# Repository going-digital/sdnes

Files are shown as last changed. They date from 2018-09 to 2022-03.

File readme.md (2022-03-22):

# SDnes
## An internal SD card modification for the Nintendo NES/SNES/Famicom/SuperFamicom classic consoles

This design is a mod-board that solders directly onto the PCB. This board allows the console to a Micro-SD card. This works well with [Hakchi](https://github.com/TeamShinkansen/hakchi2) and the tools at [Hakchi Resources](https://hakchiresources.com). The board is designed with [KiCad 5](http://kicad.org).

It is:
  * Cheap
  * Home solderable (although you will need a fine tip)
  * Compatible with Hakchi firmware
  * Tidy
  * Open source
  * NOT easy to solder. The minimal install requires soldering pads that are 1mm apart. If you are used to soldering surface mount, no problem. If not, this should not be your first project. (But it is open source, so if you want to flood eBay with them, be my guest!)
  * NOT as convenient as a ready-made board.
  * NOT suitable for users who often remove their MicroSD card. I use Hakchi to make changes remotely over USB or WiFi instead.

# Alternatives
  * [Super Storage](https://echo10.io) is a fully assembled board that allows much easier access.
  * [SD breakout boards can be handwired.](https://wiki.hakchi.net/Adding_an_Internal_SD_Card)
  * For ultimate cheapness, an SD to microSD adapter makes a functional breakout board, and everyone has a spare.

# Bill of Materials
There are two versions of this mod. If your console main board has the marking "FTM-NES", you will need the NES version. If it is marked "FTM-SHVC", you will need the SHVC version. The other components are the same.

| Component | Description | Source |
|-|-|-|
|SK1|Molex 500901-0801|RS:670-2430, Farnell:1344008, Digikey:WM19081CT-ND, Mouser:538-500901-0801, [Octopart](https://octopart.com/search?q=500901-0801)|
|PCB NES|PCB|[Oshpark](https://oshpark.com/shared_projects/vaCz66J4) or [your chosen fabricator.](https://github.com/going-digital/sdnes/tree/master/nes/fabrication)|
|or PCB SHVC|PCB|[Oshpark](https://oshpark.com/shared_projects/LHg9E5QS) or [your chosen fabricator.](https://github.com/going-digital/sdnes/tree/master/shvc/fabrication)|

Optionally card access indicator: Fit R1 (1Kohm, 0603) and D1 (Red LED, 0603).

Optional decoupling: Fit C1 (100nF, 0603)

# Fitting the NES version
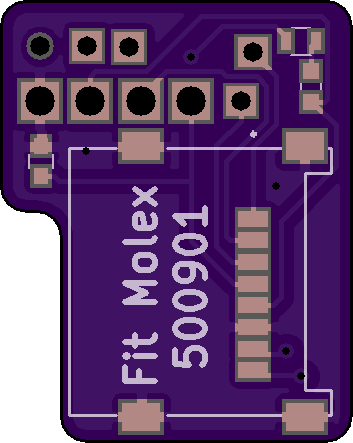
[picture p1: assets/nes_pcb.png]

* First, solder the card socket onto the mod PCB.
* Remove the metal cover plate over the console PCB.
* Mount the PCB as shown below. Hold it in place with tape, taking care to precisely align the holes with the test pads. *Image placeholder*
* While keeping the mod PCB aligned and gently pressed onto the console, flood the larger pad holes with solder.
* Then flood the smaller pad holes with solder.
* Carefully remove the tape. Apply a small amount of hot glue to mechanically secure the mod PCB down.
* Insert the prepared SD card and latch it in place.

# Fitting the SHVC version
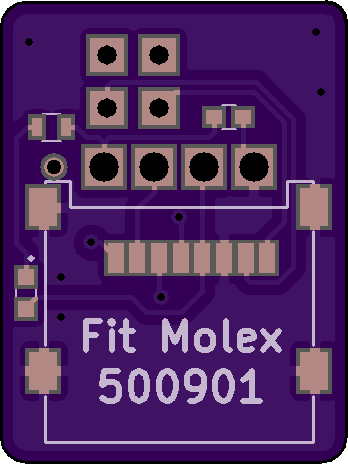
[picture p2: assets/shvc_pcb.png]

* First, solder the card socket onto the mod PCB.
* Remove the console PCB, and turn it over. The mod PCB fits on the rear.
* Mount the PCB as shown below. Hold it in place with tape, taking care to precisely align the holes with the test pads. *Image placeholder*
* While keeping the mod PCB aligned and gently pressed onto the console, flood the larger pad holes with solder.
* Then flood the smaller pad holes with solder.
* Carefully remove the tape. Apply a small amount of hot glue to mechanically secure the mod PCB down.
* Insert the prepared SD card and latch it in place.

# Licensing
This design is licensed with the [Solderpad 2.0 License](http://solderpad.org/licenses/SHL-2.0/).

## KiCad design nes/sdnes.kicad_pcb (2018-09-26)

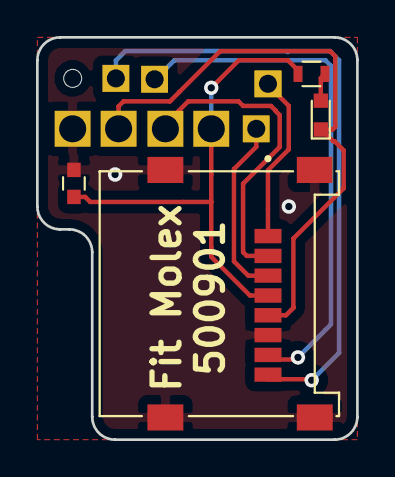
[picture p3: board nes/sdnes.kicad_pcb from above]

Board: 2 copper layers, 17.8 x 22.4 mm, 5 parts (0 on the bottom side), 9 nets.

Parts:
C2: C_Small; C_0603
D2: Red LED; LED_0603
J2: 500901-0801; MOLEX_500901-0801
R2: 1K; R_0603
SK2: nesclassic:Testpoint_cluster; FTM-NES-SD-pads

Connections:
/0V: C2.2, J2.6, J2.SH1, J2.SH2, J2.SH3, J2.SH4, SK2.6
/3V: C2.1, J2.4, R2.1, SK2.4
/CLK: D2.1, J2.5, SK2.5
/CMD: J2.3, SK2.3
/D0: J2.7, SK2.7
/D1: J2.8, SK2.8
/D2: J2.1, SK2.1
/D3: J2.2, SK2.2
unnamed: D2.2, R2.2

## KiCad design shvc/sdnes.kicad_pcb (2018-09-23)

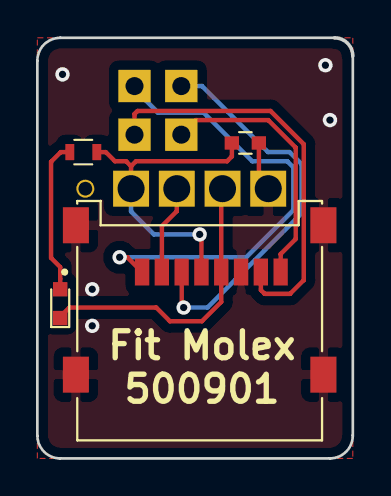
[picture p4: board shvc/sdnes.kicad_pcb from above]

Board: 2 copper layers, 17.5 x 23.4 mm, 5 parts (0 on the bottom side), 9 nets.

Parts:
C1: C_Small; C_0603
D1: Red LED; LED_0603
J1: 500901-0801; MOLEX_500901-0801
R1: 1K; R_0603
SK1: Testpoint_cluster; FTM-SHVC-SD-pads

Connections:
/0V: C1.2, J1.6, J1.SH1, J1.SH2, J1.SH3, J1.SH4, SK1.6
/3V: C1.1, J1.4, R1.1, SK1.4
/CLK: D1.1, J1.5, SK1.5
/CMD: J1.3, SK1.3
/D0: J1.7, SK1.7
/D1: J1.8, SK1.8
/D2: J1.1, SK1.1
/D3: J1.2, SK1.2
unnamed: D1.2, R1.2

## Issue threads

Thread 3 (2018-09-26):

Silkscreen error on NES version

going-digital, 2018-09-26:
NES version should reference NES, not SHVC on rear silkscreen.

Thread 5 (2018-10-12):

Check compatibility of NES and SHVC with Famicom enclosure

going-digital, 2018-10-12:
I don’t have access to a Famicom enclosure. Looking for assistance in closing this issue. It would be good to know these mods are Famicom compatible.

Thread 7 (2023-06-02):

optional Led, Res, and Cap

DecanFrost, 2023-06-02:
I cant see anywhere that tells me where to put the optional components.

I have soldered the sd card adapter to the NES and SNES pcbs from but the optional components are not labeled on the PCB or on the github

DavidARoberts, 2023-10-23:
@going-digital bumping this issue for my own benefit, I new to pcb schematics so I downloaded the KiCad file and made little to no progress figuring it out haha. If you could upload an image of a completed board it would be much appreciated. I understand this is an old project so any direction would be appreciated :)

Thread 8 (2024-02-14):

Feature request: Optional FPC extension + second PCB

aceofstax, 2024-02-14:
First of all I want to say thank you for making this availible. I think it's great that people can upload even just anything to a PCB fabricator and have a low cost professional solution. Hats off to you sir.

I don't really expect that this will be addressed being that this is has not been updated for a while, but due to the first PCB like this I've owned having been the Super Storage v3 by echo10, I can't help my fondness of the FPC cable extension. It's nice to be able to mount the SD card slot somewhere different than the solder points on the bottom of the SNES classic motherboard.

I know I've seen at least one shop surface with a closed source PCB offering the same functionality of the Super Storage v3, but I wonder if this functionality could be incorporated into this project's minimal design.

Correct me if I'm wrong here, but this seems like a minimalist PCB intentionally. As such, I would imagine it would be preferred to the author that the base PCB remains open ended to either use case: optional FPC extension & PCB, or use as currently designed.

Thinking about this, if it's possible to design this way, maybe the FPC pads should be underneath where the SDcard slot is mounted on the main PCB. Idea here is, that way an end user can't have both sd card slots mounted at the same time. Either chose the base PCB for the microSD slot location or choose the secondary PCB to mount the microSD slot, then solder the FPC connector in place of where the slot would go on the base PCB.

I'm going to attempt to learn some cad in the meantime to see if this is something I can pull off on my own. If I do make some progress I suppose I can fork this and see where it goes. I just like the open source nature and small footprint of your design. Idea is pitched with intent to keep what some would consider an unnecessary feature an option without forcing it or compromising the minimalist nature.

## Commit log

2018-08-23 Add soldermask and vias def
2018-08-23 Add SD socket
2018-08-23 Simplify board outline
2018-08-23 Move from castellated to normal plated holes
2018-08-23 Footprint tweak
2018-08-24 Mirror SD socket
2018-09-23 Functional design in Kicad
    [sdnes.kicad_pcb, sdnes.sch, sdnes2016.kicad_pcb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]
2018-09-23 Fix silkscreen
    [sdnes.kicad_pcb]
2018-09-23 Add Gerbers for manufacture
2018-09-23 Ignore gerber and drill files
2018-09-23 Mention KiCad
2018-09-26 Fix silkscreen
    Fixes issue 1
    [_saved_ssd.sch, sdnes.kicad_pcb, ssd.kicad_pcb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]
2018-09-26 Revert "Fix silkscreen"
    This reverts commit b91a6601b2e49d2b5b00c3b97c6f2e9545f83911.
    [_saved_ssd.sch, sdnes.kicad_pcb, ssd.kicad_pcb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]
2021-11-09 Update readme.md
    https://forum.kicad.info/t/warning-avoid-all-links-to-kicad-pcb-org-use-kicad-org/31521
